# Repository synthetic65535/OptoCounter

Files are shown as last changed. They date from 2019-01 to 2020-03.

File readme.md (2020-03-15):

# OptoCounter
Электронный счетчик импульсов.

* Используемый микроконтроллер: atmega8
* Среда разработки: KiCad
* Прошивка для микроконтроллера: [Здесь](https://github.com/synthetic65535/OptoCounterFirmware)

Отличительные особенности счетчика:
 * Возможность использовать самые разнообразные датчики, изменяющие во время работы свою проводимость: фоторезисторы, фототранзисторы, микрофоны...
 * Аппаратный фильтр, заглушающий помехи от 50 герц и выше
 * Аппаратный дифференциатор + компаратор с гистерезисом. При необходимости можно сделать подстройку схемы под конкретный датчик не изменяя прошивку микроконтроллера. Микроконтроллер не занимается фильтрацией сигнала, ему на вход подаются уже готовые прямоугольные импульсы, которые он считает.
 * Отсутствие SMD деталей
 * Питание от USB

Device Photo

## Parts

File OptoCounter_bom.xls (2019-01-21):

Элемент | Номинал | Количество | Обозначение на схеме | Где купить | Стоимость за 1 | Стоимость за N
Диод | 1N4148/1N4007 | 3 | D1, D2, D3 | https://www.chipdip.ru/product/1n4148 | 2 | 6
Кварцевый резонатор | 8Mhz | 1 | Y1 | https://www.chipdip.ru/product/8mhz-hc-49s | 15 | 15
Микроконтроллер | ATMEGA8A-PU | 1 | U2 | https://www.chipdip.ru/product/atmega8a-pu | 95 | 95
Транзистор NPN/N-канальный | Любой на ток 100мА | 3 | Q1, Q2, Q3 | https://www.chipdip.ru/product/bs170-onsemi | 6 | 18
Светодиодный индикатор | BC56-12SRWA | 1 | U3 | https://www.chipdip.ru/product/bc56-12srwa | 180 | 180
Разъем 2x3 штырьковый | IDC-06 или PLD-6 | 1 | J2 | https://www.chipdip.ru/product/idc-06ms-bh-06 | 6 | 6
Операционные усилители | LM358N | 1 | U1 | https://www.chipdip.ru/product/lm358n-stm | 27 | 27
Разъемы RCA | RS-212 | 1 | J1 | https://www.chipdip.ru/product/rs-212 | 30 | 30
Микропереключатель | MSW-11 | 1 | SW1 | https://www.chipdip.ru/product/sm5-00n-115-msw-11 | 40 | 40
Разъем USB на плату | USBB-1J | 1 | J3 | https://www.chipdip.ru/product/usbb-1j | 23 | 23
Резистор | 470 ом | 9 | R1, R15, R16, R17, R18, R19, R20, R21, R22 | https://www.chipdip.ru/product0/22560 | 2 | 18
Резистор | 22кОм | 2 | R4, R8 | https://www.chipdip.ru/product0/40844 | 2 | 4
Резистор | 1кОм | 7 | R2, R11, R26, R24, R27, R28, R14 | https://www.chipdip.ru/product0/44435 | 2 | 14
Резистор | 10кОм | 6 | R3, R5, R7, R9, R12, R13 | https://www.chipdip.ru/product0/48560 | 2 | 12
Резистор | 10Ом | 1 | R23 | https://www.chipdip.ru/product0/48560 | 2 | 2
Резистор | 1МОм | 1 | R6 | https://www.chipdip.ru/product0/51741 | 2 | 2
Конденсатор электролитический | 330uF | 1 | C7 | https://www.chipdip.ru/product0/9000247219 | 14 | 14
Конденсатор керамический | 0.1uF | 3 | C2, C3, C4 | https://www.chipdip.ru/product0/9000313101 | 20 | 60
Конденсатор керамический | 22pF | 2 | C5, C6 | https://www.chipdip.ru/product0/9000313106 | 9 | 18
Конденсатор керамический | 4.7-10uF | 1 | C1 | https://www.chipdip.ru/product0/9000313115 | 18 | 18
Резистор | 100кОм | 1 | R10 | https://www.chipdip.ru/product0/9549 | 3 | 3
Цанговая панелька | TRS-28 | 1 | U2 | https://www.chipdip.ru/product/trs-28 | 40 | 40
Цанговая панелька | TRL-24 | 1 | U3 | https://www.chipdip.ru/product/trl-24 | 30 | 30
Цанговая панелька | TRS-8 | 1 | U1 | https://www.chipdip.ru/product/trs-8 | 12 | 12
Стабилитрон на 5.6В | 1N4734A | 1 | D4 | https://www.chipdip.ru/product/1n4734a | 4 | 4
 |  |  |  |  |  | 0
Корпус | "Адаптивный" | 1 |  | https://www.chipdip.ru/product0/9000064774 | 140 | 140
Винт, полукруглая шляпка | М2.5*6 | 4 |  | https://www.chipdip.ru/product0/9000071824 |  | 0
Шуруп, потайная шляпка | М2.5*20 | 4 |  |  |  | 0
Светодиод ультрафиолетовый |  | 1 |  | https://www.chipdip.ru/product/bl-l522vc | 23 | 23
Фототранзистор |  | 1 |  | https://www.chipdip.ru/product/l-53p3c | 11 | 11
Шляпка от тактовой кнопки | 12*12*8 | 1 |  | https://www.chipdip.ru/product/kan1211-0801b | 6 | 6
RCA кабель |  | 1 |  | https://www.chipdip.ru/product0/8020909113 | 30 | 30
 |  |  |  |  | Сумма | 901

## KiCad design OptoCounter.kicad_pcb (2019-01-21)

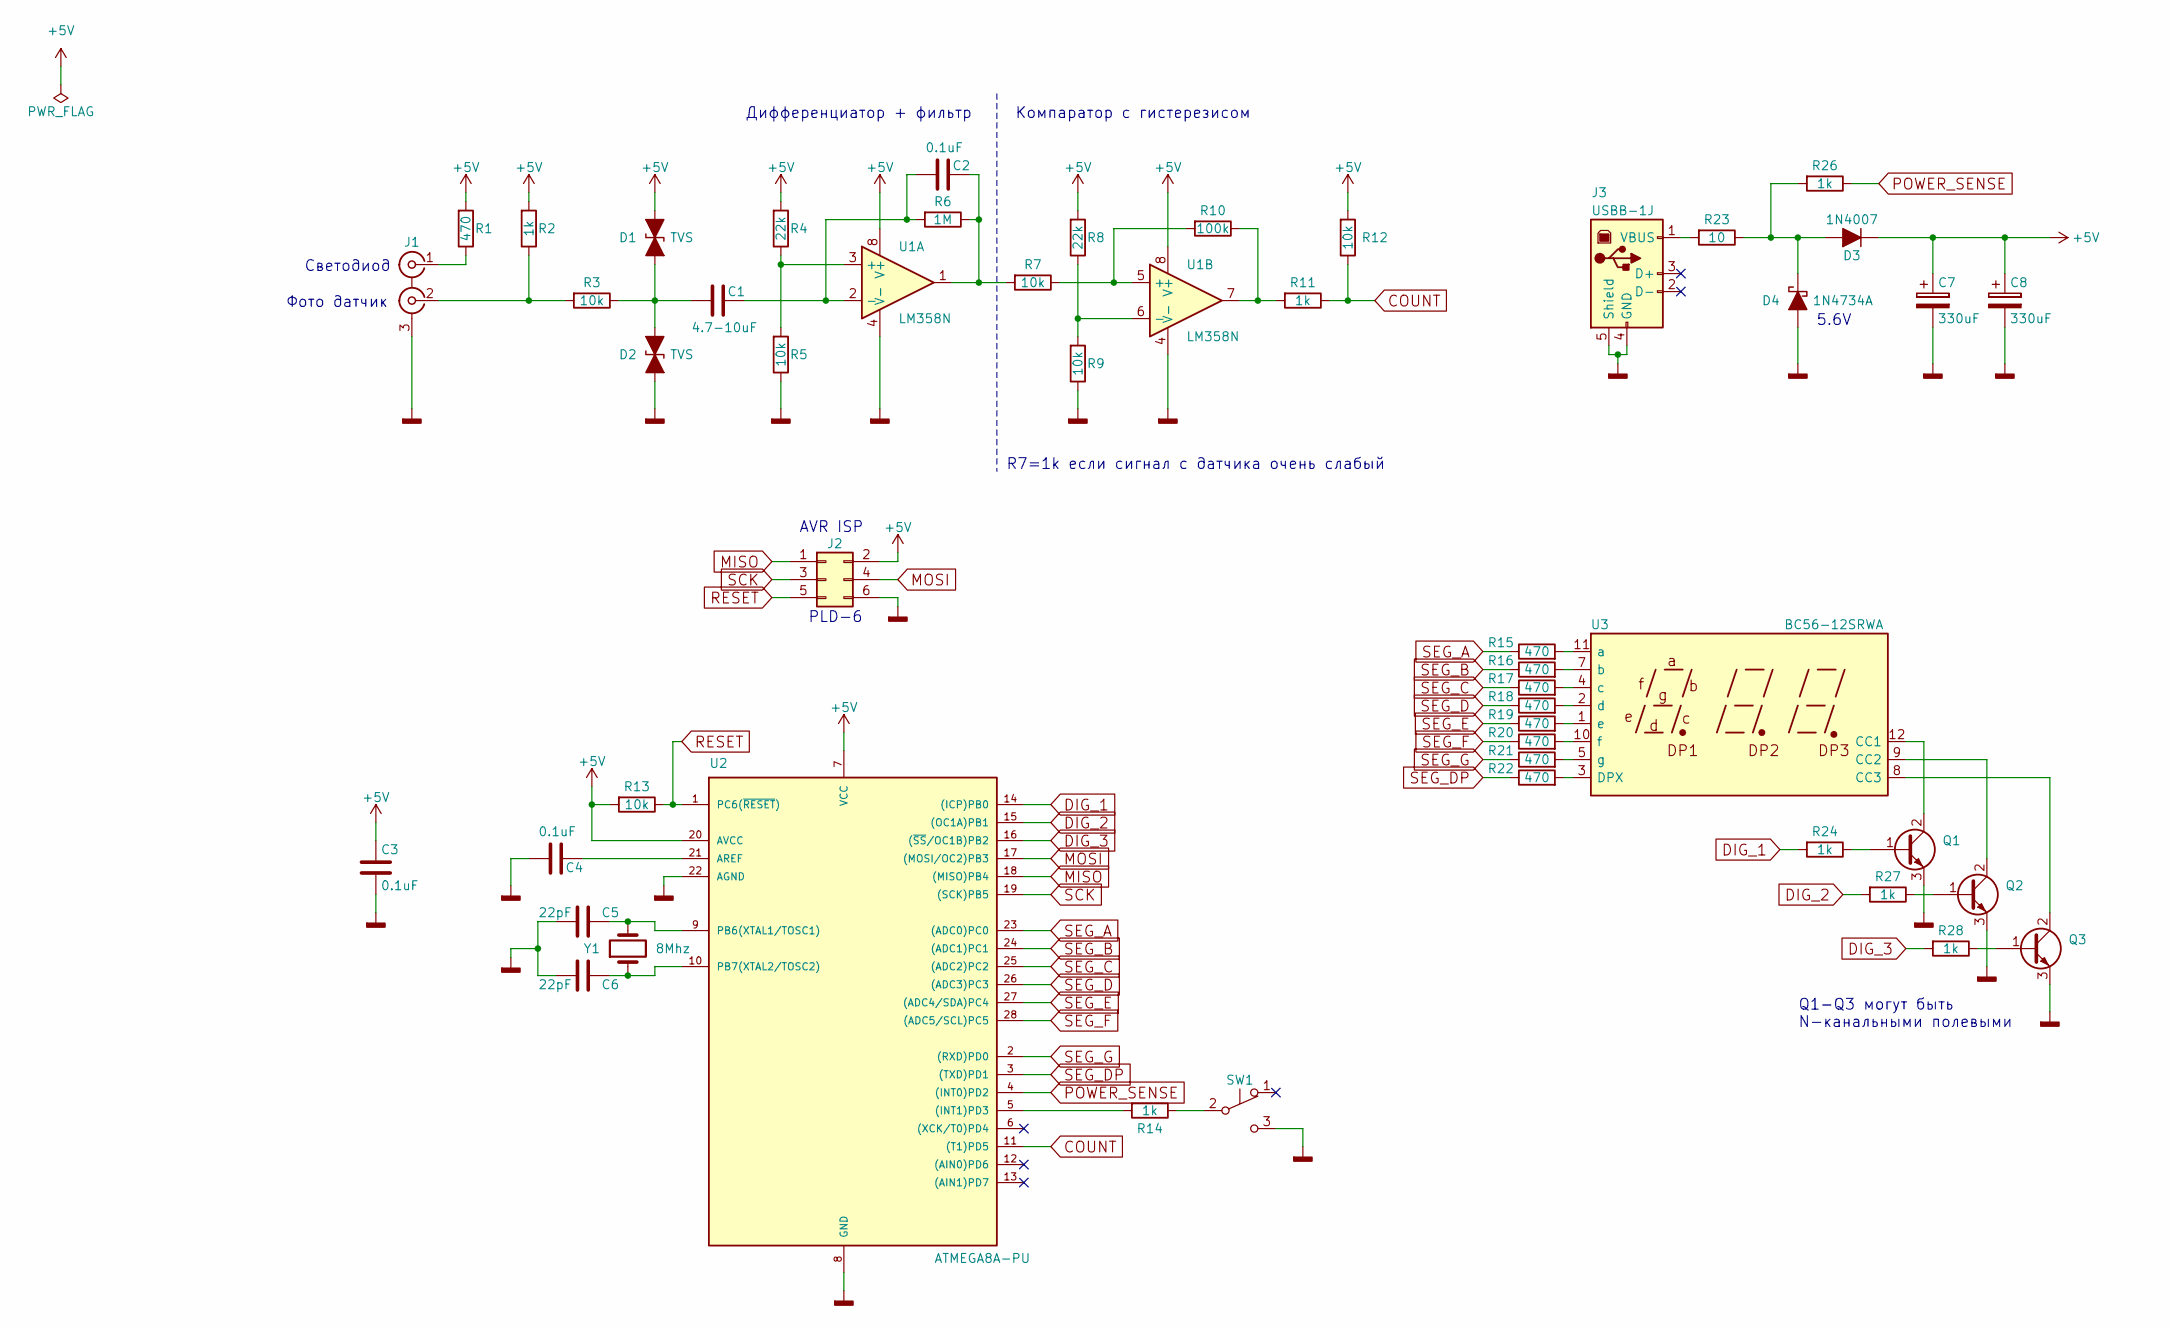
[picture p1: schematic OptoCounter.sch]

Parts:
C1: 4.7-10uF; CAP
C2, C3, C4: 0.1uF; CAP
C5, C6: 22pF; CAP
C7, C8: 330uF; CP_Radial_D6.3mm_P2.50mm
D1, D2: TVS; DO-41
D3: 1N4007; DO-41
D4: 1N4734A; DO-41
J1: RS-212; RS212
J2: PLD-6; AVR_ISP
J3: USBB-1J; USB_B
Q1, Q2, Q3: Q_NPN_BCE; Q_BCE
R1, R15, R16, R17, R18, R19, R20, R21, R22: 470; RES
R2, R11, R14, R24, R26, R27, R28: 1k; RES
R3, R5, R7, R9, R12, R13: 10k; RES
R4, R8: 22k; RES
R6: 1M; RES
R10: 100k; RES
R23: 10; RES
SW1: MSW-11; SM5-00N-115
U1: LM358N; DIP-8_W7.62mm_Socket
U2: ATMEGA8A-PU; TRS-28_Connfly
U3: BC56-12SRWA
Y1: 8Mhz; Crystal_HC49-4H_Vertical

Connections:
+5V: C3.1, C7.1, C8.1, D1.1 (A1), D3.1 (K), J2.2, R1.2, R2.2, R4.2, R8.2, R12.2, R13.2, U1.8 (V+), U2.7 (VCC), U2.20 (AVCC)
COUNT: R11.1, R12.1, U2.11 ((T1)PD5)
DIG_1: R24.2, U2.14 ((ICP)PB0)
DIG_2: R27.2, U2.15 ((OC1A)PB1)
DIG_3: R28.2, U2.16 ((~SS~/OC1B)PB2)
GNDD: C3.2, C4.2, C5.2, C6.2, C7.2, C8.2, D2.2 (A2), D4.2 (A), J1.3 (EXT), J2.6, J3.4 (GND), J3.5 (Shield), Q1.3 (E), Q2.3 (E), Q3.3 (E), R5.1, R9.1, SW1.3 (C), U1.4 (V-), U2.8 (GND), U2.22 (AGND)
MISO: J2.1, U2.18 ((MISO)PB4)
MOSI: J2.4, U2.17 ((MOSI/OC2)PB3)
unnamed: C1.1, C2.2, R6.2, U1.2 (-)
unnamed: C1.2, D1.2 (A2), D2.1 (A1), R3.1
unnamed: C2.1, R6.1, R7.2, U1.1
unnamed: C4.1, U2.21 (AREF)
unnamed: C5.1, U2.9 (PB6(XTAL1/TOSC1)), Y1.2
unnamed: C6.1, U2.10 (PB7(XTAL2/TOSC2)), Y1.1
unnamed: D3.2 (A), D4.1 (K), R23.1, R26.2
unnamed: J1.1 (IN1), R1.1
unnamed: J1.2 (IN2), R2.1, R3.2
unnamed: J3.1 (VBUS), R23.2
unnamed: Q1.1 (B), R24.1
unnamed: Q1.2 (C), U3.12 (CC1)
unnamed: Q2.1 (B), R27.1
unnamed: Q2.2 (C), U3.9 (CC2)
unnamed: Q3.1 (B), R28.1
unnamed: Q3.2 (C), U3.8 (CC3)
unnamed: R4.1, R5.2, U1.3 (+)
unnamed: R8.1, R9.2, U1.6 (-)
unnamed: R10.1, R11.2, U1.7
unnamed: R7.1, R10.2, U1.5 (+)
unnamed: R14.1, SW1.2 (B)
unnamed: R14.2, U2.5 ((INT1)PD3)
unnamed: R15.2, U3.11 (a)
unnamed: R16.2, U3.7 (b)
unnamed: R17.2, U3.4 (c)
unnamed: R18.2, U3.2 (d)
unnamed: R19.2, U3.1 (e)
unnamed: R20.2, U3.10 (f)
unnamed: R21.2, U3.5 (g)
unnamed: R22.2, U3.3 (DPX)
POWER_SENSE: R26.1, U2.4 ((INT0)PD2)
RESET: J2.5, R13.1, U2.1 (PC6(~RESET~))
SCK: J2.3, U2.19 ((SCK)PB5)
SEG_A: R15.1, U2.23 ((ADC0)PC0)
SEG_B: R16.1, U2.24 ((ADC1)PC1)
SEG_C: R17.1, U2.25 ((ADC2)PC2)
SEG_D: R18.1, U2.26 ((ADC3)PC3)
SEG_DP: R22.1, U2.3 ((TXD)PD1)
SEG_E: R19.1, U2.27 ((ADC4/SDA)PC4)
SEG_F: R20.1, U2.28 ((ADC5/SCL)PC5)
SEG_G: R21.1, U2.2 ((RXD)PD0)

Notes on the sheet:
Фото датчик
R7=1k если сигнал с датчика очень слабый
Компаратор с гистерезисом
Дифференциатор + фильтр
Светодиод
PLD-6
AVR ISP
5.6V
Q1-Q3 могут быть N-канальными полевыми

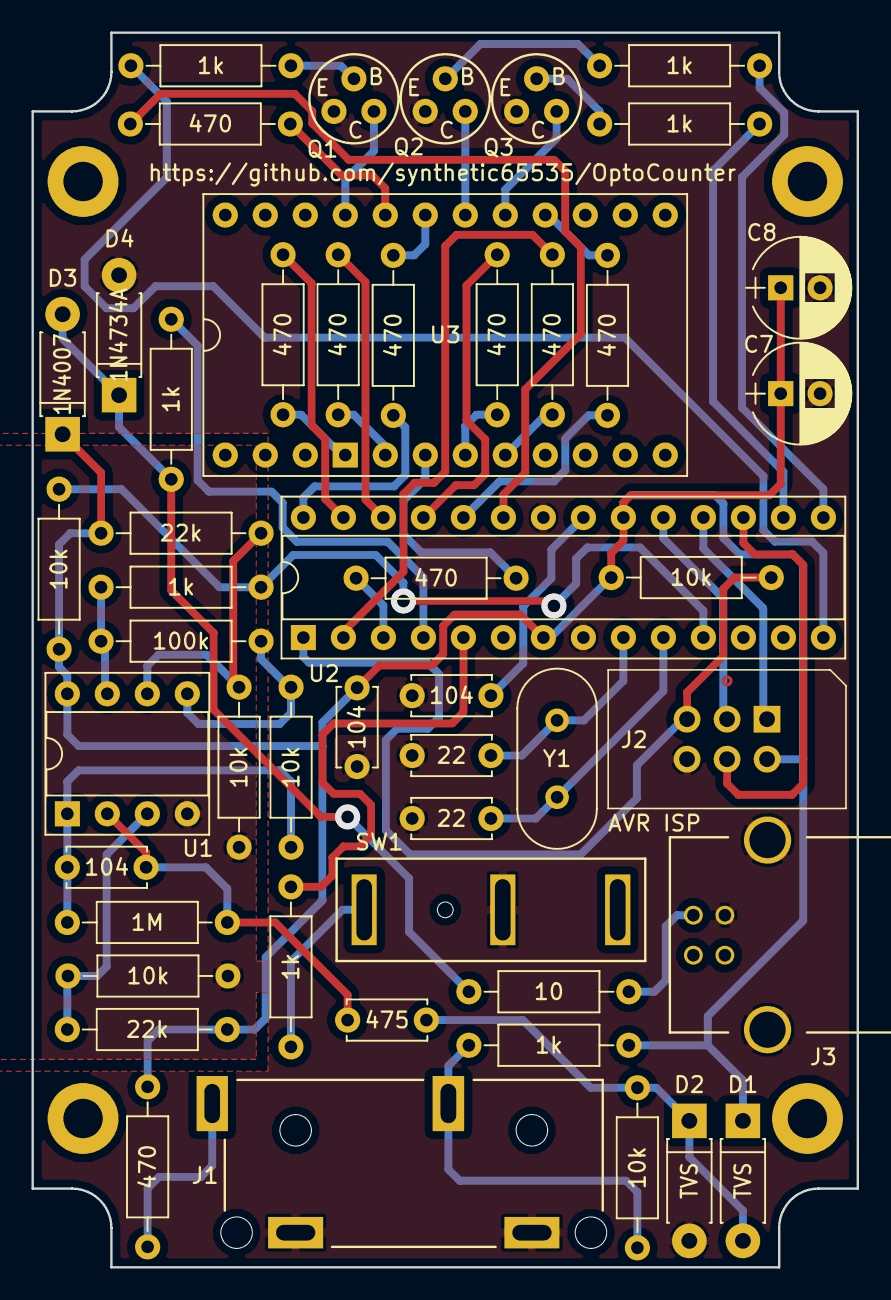
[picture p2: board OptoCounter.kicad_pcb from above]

Board: 2 copper layers, 52.4 x 78.4 mm, 50 parts (0 on the bottom side), 49 nets.
